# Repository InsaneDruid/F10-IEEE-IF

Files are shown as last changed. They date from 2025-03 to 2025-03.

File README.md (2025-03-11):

# F10-IEEE-IF - a CBM6400 / StarWriter F10 IEEE-488 interface clone
A 100% compatible replica of the F10-IEEE-IF IEEE-488 internal interface board used in the CBM 6400 daisy-wheel printer to convert the parallel interface of its StarWriter F10-based internals to the IEEE-488 bus used in the CBM PET series computers. 

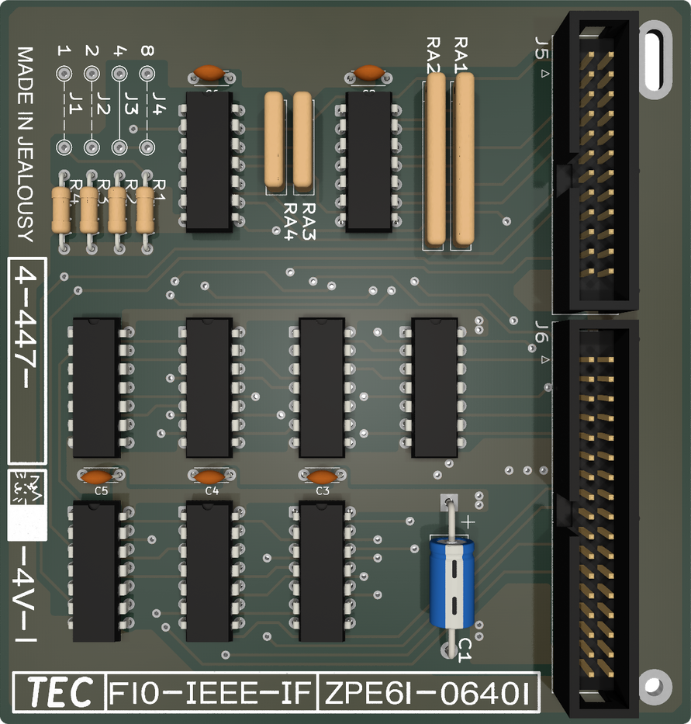
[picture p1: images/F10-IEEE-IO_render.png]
F10-IEEE-IF render


[Schematic](https://github.com/InsaneDruid/F10-IEEE-IF/blob/main/F10-IEEE-IF.pdf "Schematic")  

[Bill of Materials](https://htmlpreview.github.io/?https://github.com/InsaneDruid/F10-IEEE-IF/blob/main/bom/F10-IEEE-IF_bom.html "Bill of Materials")

## The IEEE-488 device number
There are 4 jumpers on the interface card that define the device number under which the printer can be accessed.
Set them according to the table:

| device number | J1 | J2 | J3 | J4 |
|---|----|----|----|----|
| 1 | 1  | 0  | 0  | 0  |
| 2 | 0  | 1  | 0  | 0  |
| 3 | 1  | 1  | 0  | 0  |
| 4 (default) | 0  | 0  | 1  | 0  |
| 5 | 1  | 0  | 1  | 0  |
| 6 | 0  | 1  | 1  | 0  |
| 7 | 1  | 1  | 1  | 0  |
| 8 | 0  | 0  | 0  | 1  |
| 9 | 1  | 0  | 0  | 1  |
| 10 | 0  | 1  | 0  | 1  |
| 11 | 1  | 1  | 0  | 1  |
| 12 | 0  | 0  | 1  | 1  |
| 13 | 1  | 0  | 1  | 1  |
| 14 | 0  | 1  | 1  | 1  |
| 15 | 1  | 1  | 1  | 1  |

## The License
This work is licensed under a Creative Commons Attribution-ShareAlike 4.0 International License.   
See https://creativecommons.org/licenses/by-sa/4.0/.

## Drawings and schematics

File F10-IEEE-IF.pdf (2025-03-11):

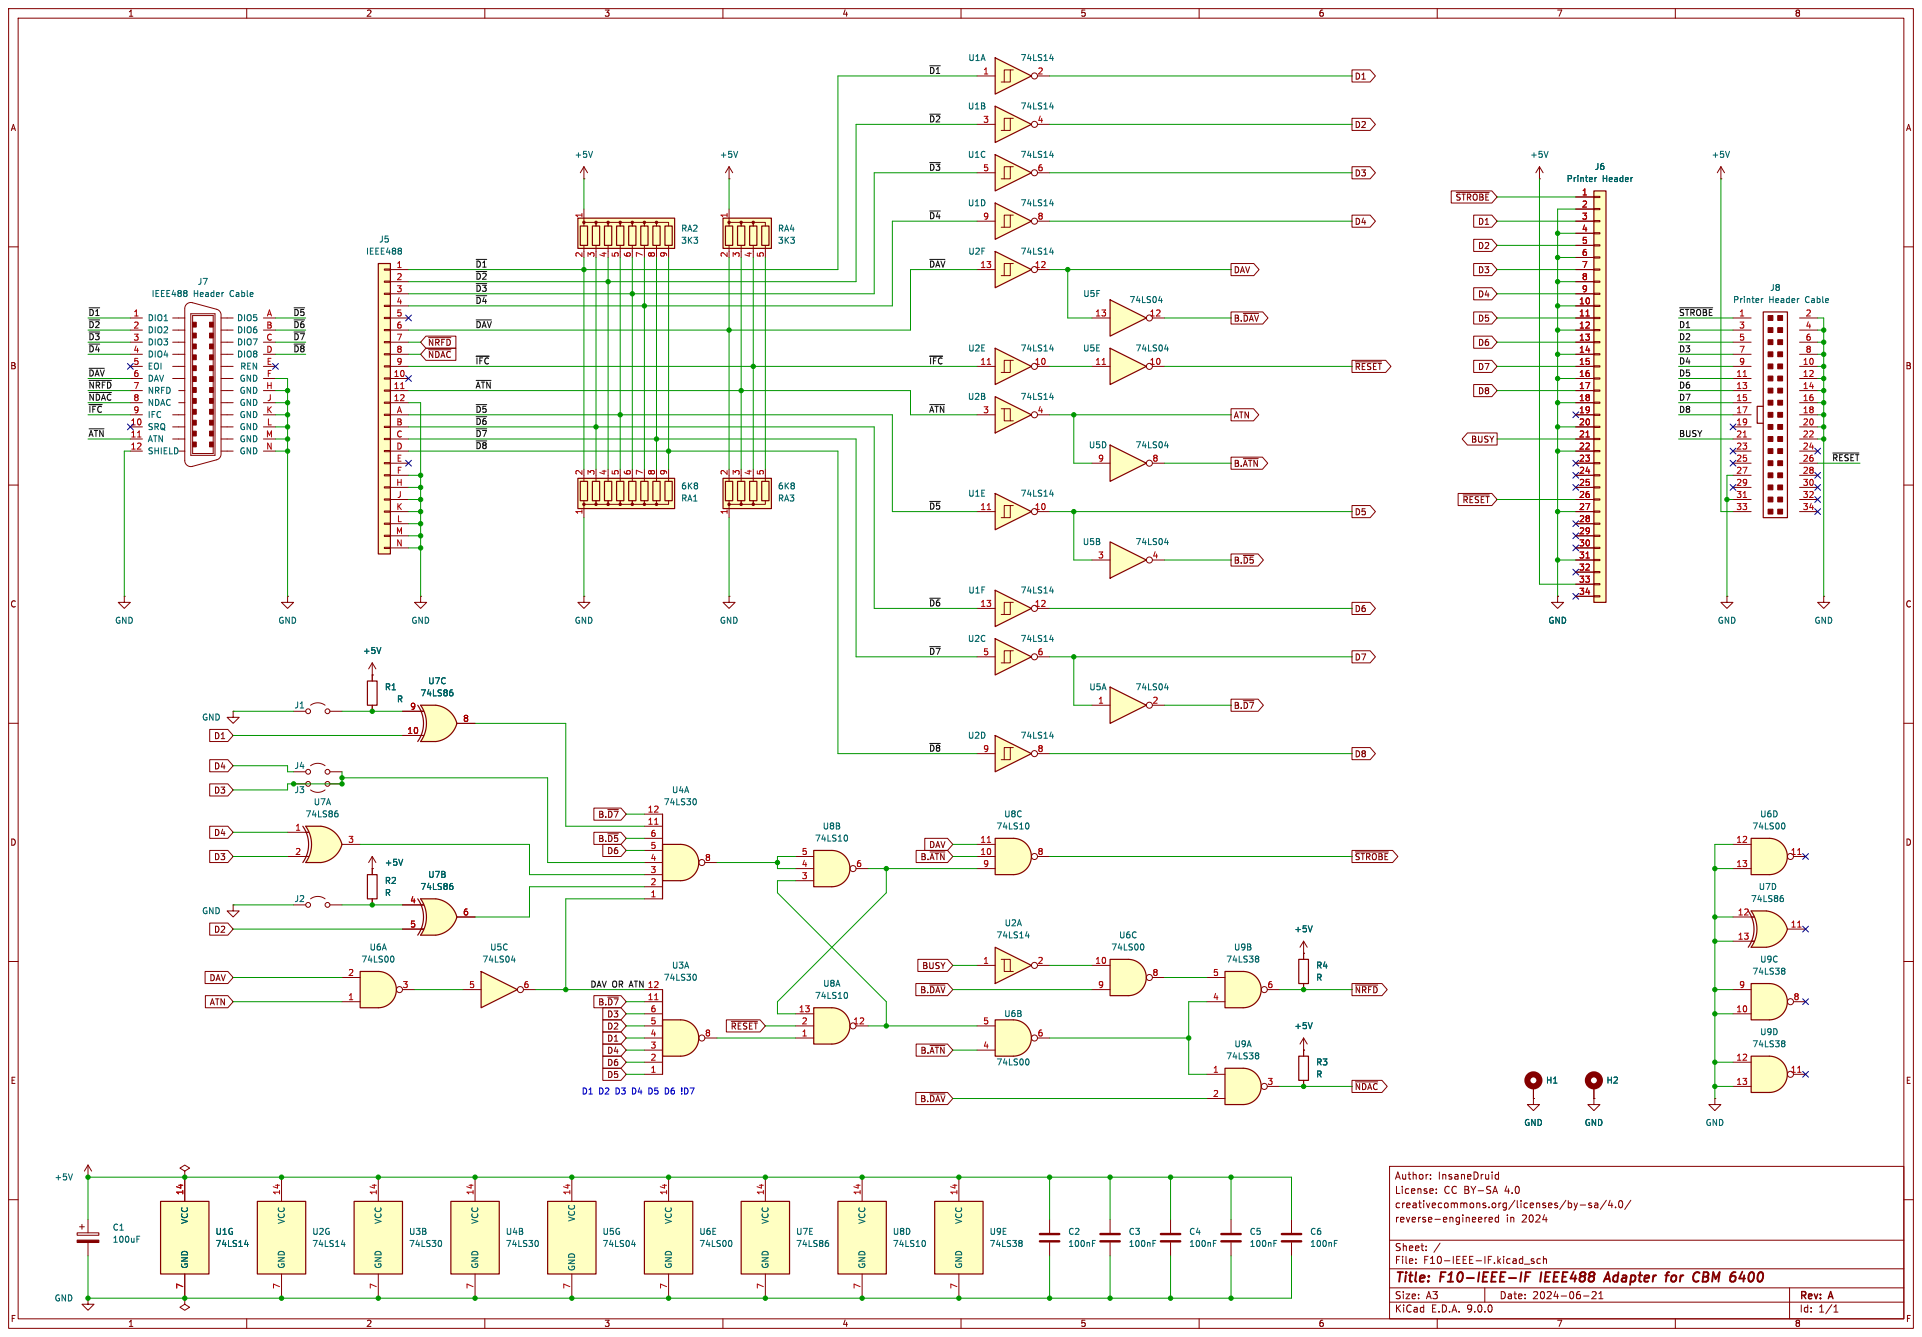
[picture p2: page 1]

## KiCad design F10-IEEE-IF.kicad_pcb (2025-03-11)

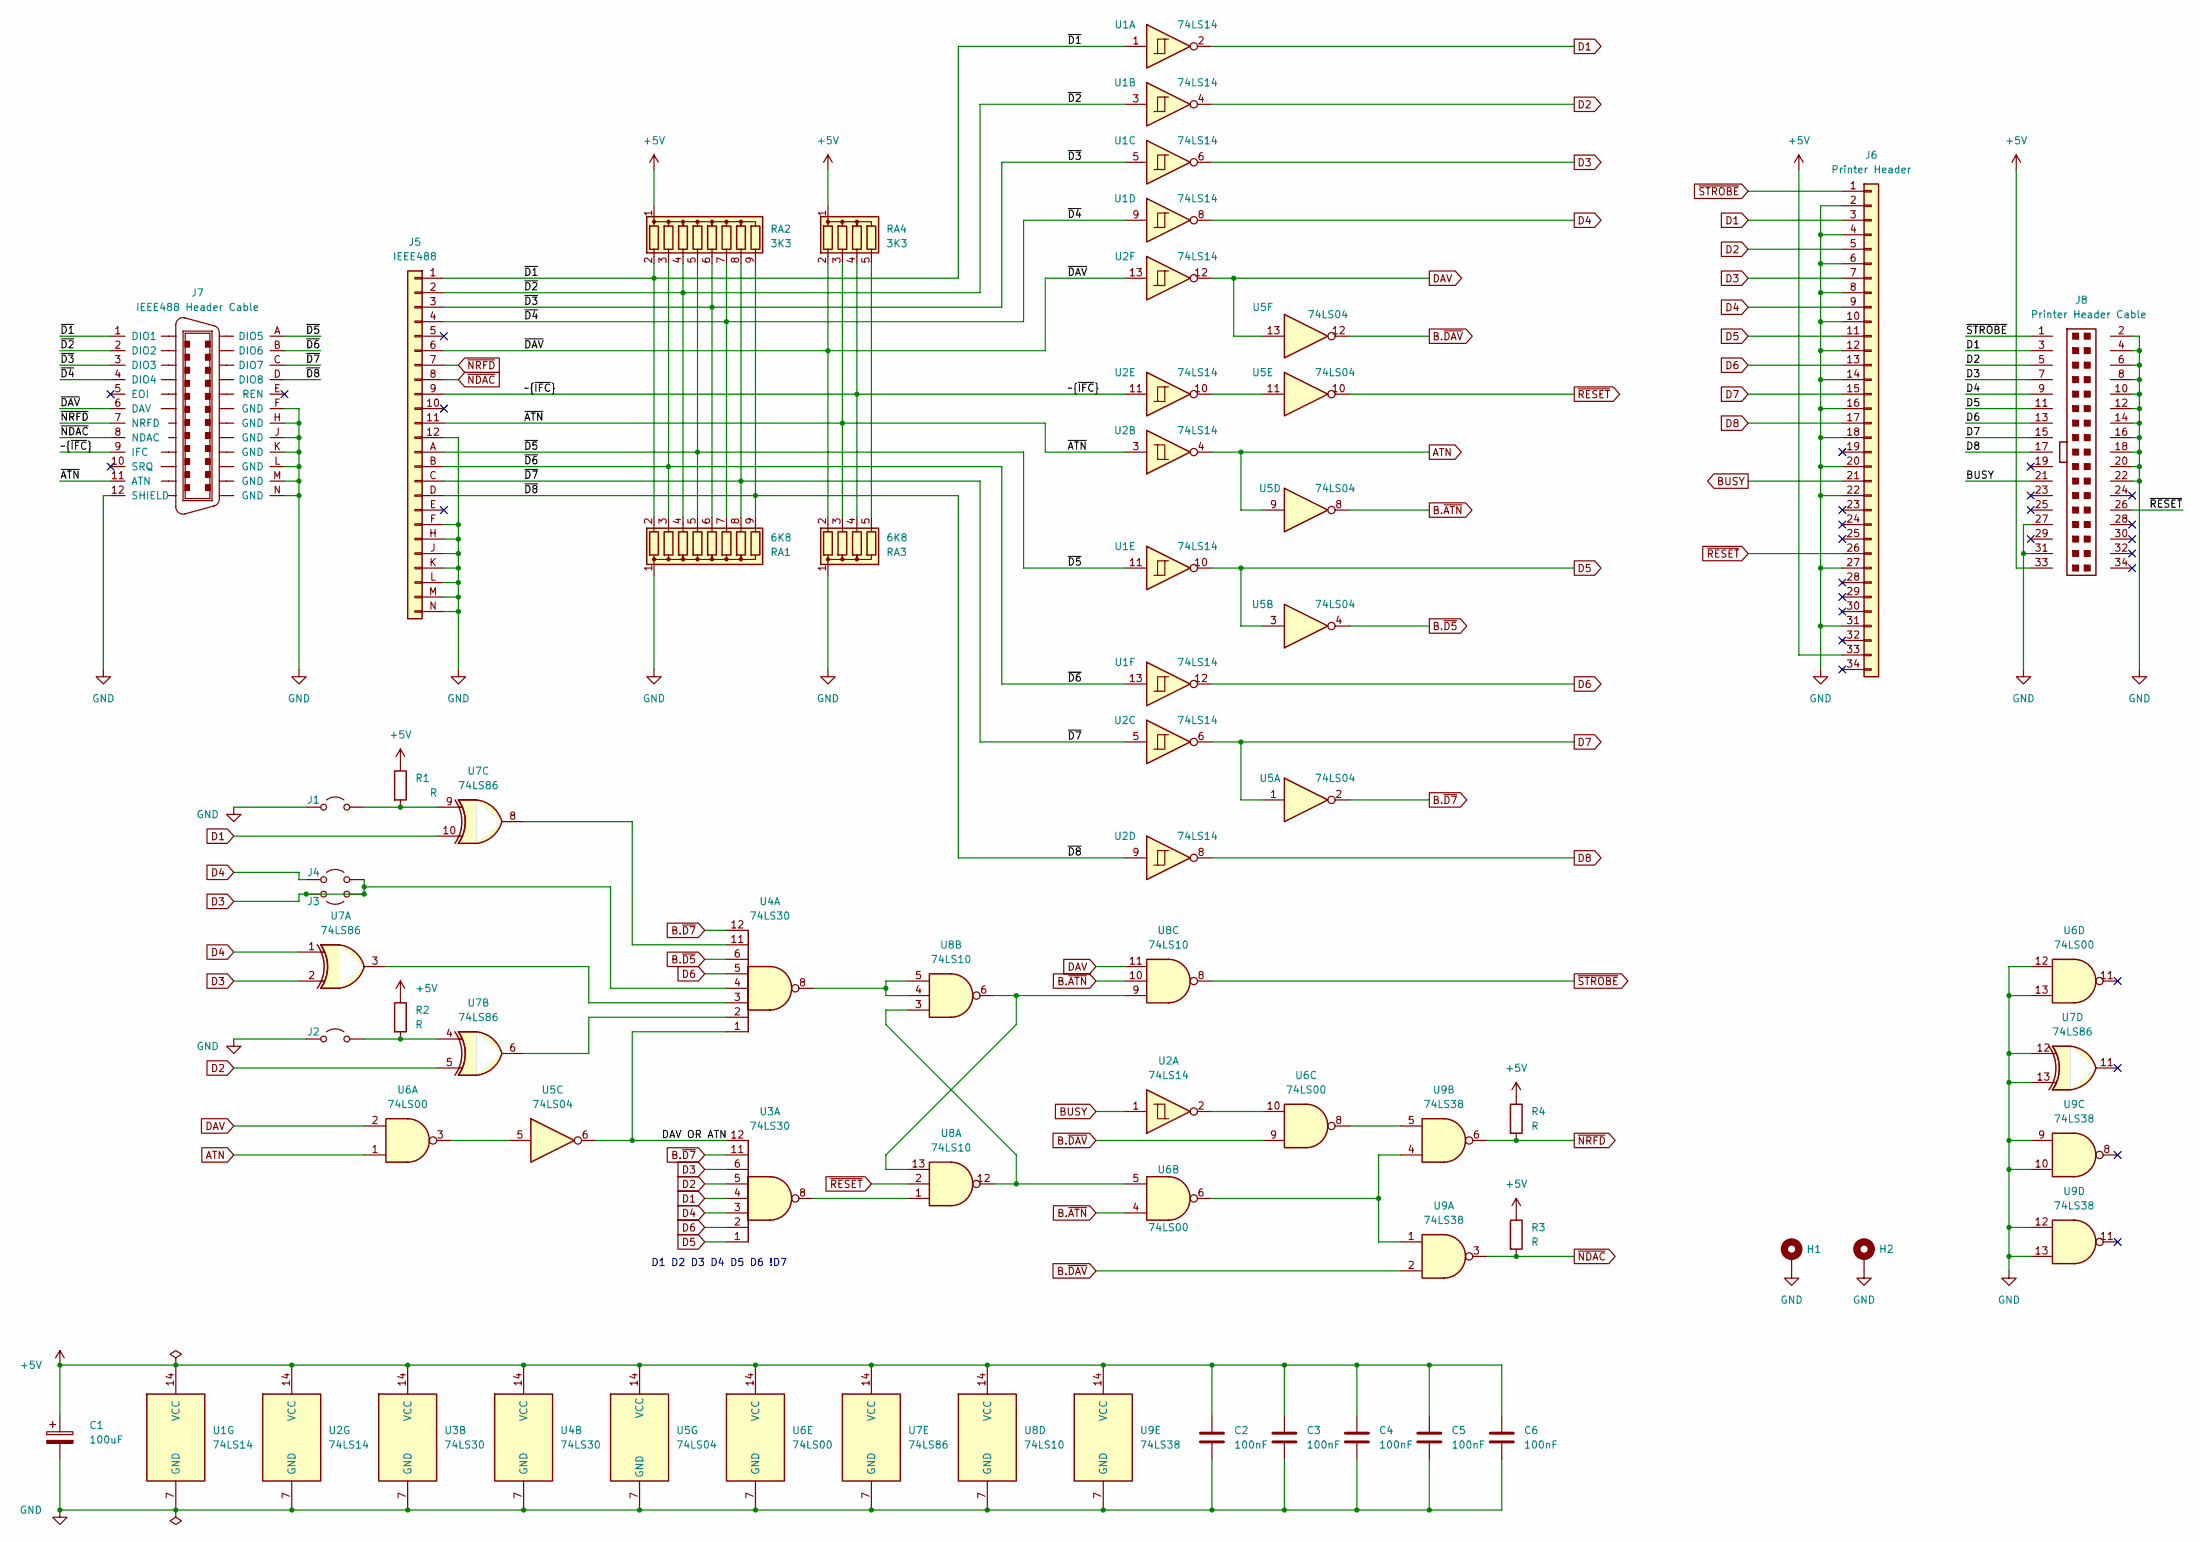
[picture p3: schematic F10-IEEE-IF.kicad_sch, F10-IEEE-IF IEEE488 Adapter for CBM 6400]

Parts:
C1: 100uF; CP_Axial_L11.0mm_D5.0mm_P20.32mm_Horizontal
C2, C3, C4, C5, C6: 100nF; C_Disc_D4.3mm_W1.9mm_P5.00mm
H1: MountingHole_Pad; MountingHole_2.5mm_Pad
H2: MountingHole_Pad; MountingHole_2.5mm_Pad_Slot
J1, J2, J3, J4: Jumper_2_Open; Jumper_Wire
J5: IEEE488; IDC-Header_2x12_P2.54mm_Vertical
J6: Printer Header; IDC-Header_2x17_P2.54mm_Vertical
J7: IEEE488 Header Cable; centronix-24-female
J8: Printer Header Cable
R1, R2, R3, R4: R; R_Axial_DIN0207_L6.3mm_D2.5mm_P10.16mm_Horizontal
RA1: 6K8; R_Array_SIP9
RA2: 3K3; R_Array_SIP9
RA3: 6K8; R_Array_SIP5
RA4: 3K3; R_Array_SIP5
U1, U2: 74LS14; DIP-14_W7.62mm
U3, U4: 74LS30; DIP-14_W7.62mm
U5: 74LS04; DIP-14_W7.62mm
U6: 74LS00; DIP-14_W7.62mm
U7: 74LS86; DIP-14_W7.62mm
U8: 74LS10; DIP-14_W7.62mm
U9: 74LS38; DIP-14_W7.62mm

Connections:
+5V: C1.1, C2.1, C3.1, C4.1, C5.1, C6.1, J6.33, J8.33, R1.1, R2.1, R3.1, R4.1, RA2.1 (common), RA4.1 (common), U1.14 (VCC), U2.14 (VCC), U3.14 (VCC), U4.14 (VCC), U5.14 (VCC), U6.14 (VCC), U7.14 (VCC), U8.14 (VCC), U9.14 (VCC)
/DAV OR ATN: U3.12, U4.1, U5.6
/~ATN: J5.11 (ATN), J7.11 (ATN), RA3.3 (R2), RA4.3 (R2), U2.3
/~D1: J5.1 (DIO1), J7.1 (DIO1), RA1.2 (R1), RA2.2 (R1), U1.1
/~D2: J5.2 (DIO2), J7.2 (DIO2), RA1.4 (R3), RA2.4 (R3), U1.3
/~D3: J5.3 (DIO3), J7.3 (DIO3), RA1.6 (R5), RA2.6 (R5), U1.5
/~D4: J5.4 (DIO4), J7.4 (DIO4), RA1.7 (R6), RA2.7 (R6), U1.9
/~D5: J5.A (DIO5), J7.A (DIO5), RA1.5 (R4), RA2.5 (R4), U1.11
/~D6: J5.B (DIO6), J7.B (DIO6), RA1.3 (R2), RA2.3 (R2), U1.13
/~D7: J5.C (DIO7), J7.C (DIO7), RA1.8 (R7), RA2.8 (R7), U2.5
/~D8: J5.D (DIO8), J7.D (DIO8), RA1.9 (R8), RA2.9 (R8), U2.9
/~DAV: J5.6 (DAV), J7.6 (DAV), RA3.2 (R1), RA4.2 (R1), U2.13
/~~{IFC}: J5.9 (IFC), J7.9 (IFC), RA3.4 (R3), RA4.4 (R3), U2.11
ATN: U2.4, U5.9, U6.1
B.~ATN: U5.8, U6.4, U8.10
B.~D5: U4.6, U5.4
B.~D7: U3.11, U4.12, U5.2
B.~DAV: U5.12, U6.9, U9.2
BUSY: J6.21, U2.1
D1: J6.3, U1.2, U3.4, U7.10
D2: J6.5, U1.4, U3.5, U7.5
D3: J3.1 (A), J3.2 (B), J4.2 (B), J6.7, U1.6, U3.6, U4.4, U7.2
D4: J4.1 (A), J6.9, U1.8, U3.3, U7.1
D5: J6.11, U1.10, U3.1, U5.3
D6: J6.13, U1.12, U3.2, U4.5
D7: J6.15, U2.6, U5.1
D8: J6.17, U2.8
DAV: U2.12, U5.13, U6.2, U8.11
GND: C1.2, C2.2, C3.2, C4.2, C5.2, C6.2, H1.1, H2.1, J1.1 (A), J2.1 (A), J5.12 (SHIELD), J5.F (GND), J5.H (GND), J5.J (GND), J5.K (GND), J5.L (GND), J5.M (GND), J5.N (GND), J6.2, J6.4, J6.6, J6.8, J6.10, J6.12, J6.14, J6.16, J6.18, J6.20, J6.22, J6.27, J6.31, J7.12 (SHIELD), J7.F (GND), J7.H (GND), J7.J (GND), J7.K (GND), J7.L (GND), J7.M (GND), J7.N (GND), J8.2, J8.4, J8.6, J8.8, J8.10, J8.12, J8.14, J8.16, J8.18, J8.20, J8.22, J8.27, J8.31, RA1.1 (common), RA3.1 (common), U1.7 (GND), U2.7 (GND), U3.7 (GND), U4.7 (GND), U5.7 (GND), U6.7 (GND), U6.12, U6.13, U7.7 (GND), U7.12, U7.13, U8.7 (GND), U9.7 (GND), U9.9, U9.10, U9.12, U9.13
unnamed: J1.2 (B), R1.2, U7.9
unnamed: J2.2 (B), R2.2, U7.4
unnamed: RA3.5 (R4), RA4.5 (R4)
unnamed: U2.2, U6.10
unnamed: U2.10, U5.11
unnamed: U3.8, U8.1
unnamed: U4.2, U7.6
unnamed: U4.3, U7.3
unnamed: U4.8, U8.4, U8.5
unnamed: U4.11, U7.8
unnamed: U5.5, U6.3
unnamed: U6.5, U8.3, U8.12
unnamed: U6.6, U9.1, U9.4
unnamed: U6.8, U9.5
unnamed: U8.6, U8.9, U8.13
~NDAC: J5.8 (NDAC), R3.2, U9.3
~NRFD: J5.7 (NRFD), R4.2, U9.6
~RESET: J6.26, U5.10, U8.2
~STROBE: J6.1, U8.8

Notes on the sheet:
D1 D2 D3 D4 D5 D6 !D7

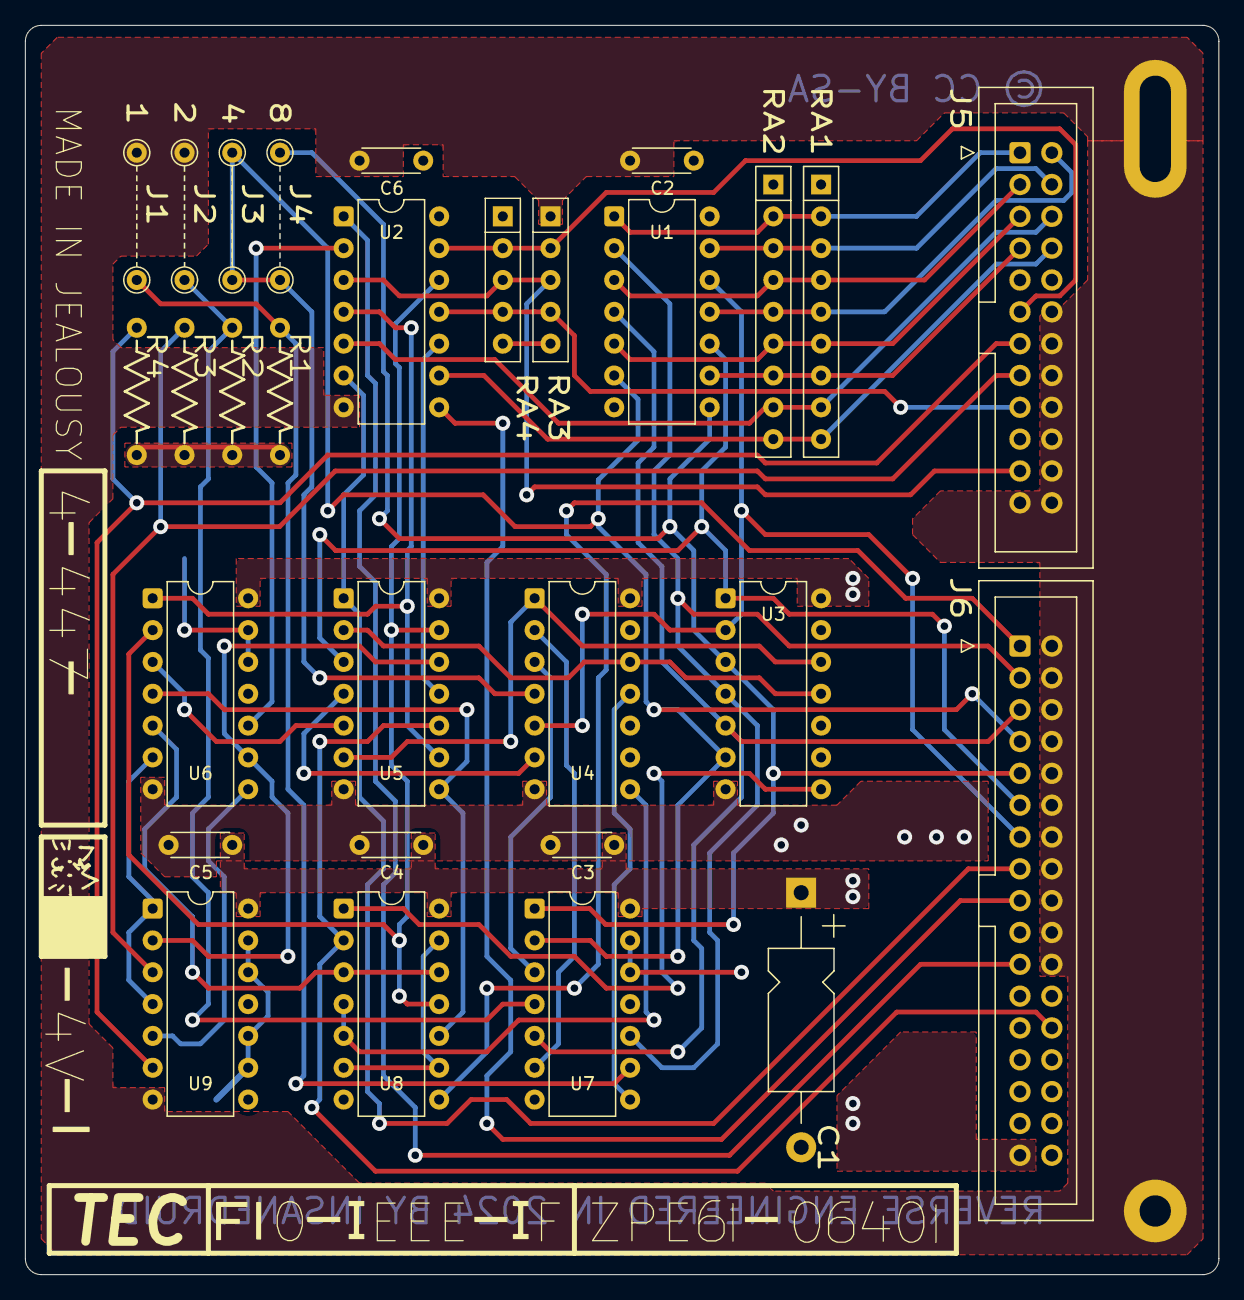
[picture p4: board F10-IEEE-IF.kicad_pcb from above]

Board: 2 copper layers, 95.2 x 99.7 mm, 31 parts (0 on the bottom side), 48 nets.

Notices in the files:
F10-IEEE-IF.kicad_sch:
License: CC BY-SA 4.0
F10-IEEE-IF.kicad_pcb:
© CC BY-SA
